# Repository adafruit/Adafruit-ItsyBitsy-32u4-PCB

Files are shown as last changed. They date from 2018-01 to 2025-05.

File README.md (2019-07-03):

## Adafruit ItsyBitsy 32u4 PCB

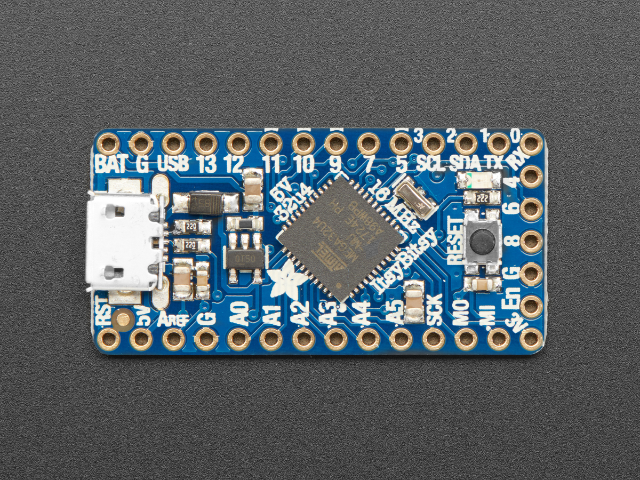
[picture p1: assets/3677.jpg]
<a href="http://www.adafruit.com/products/3677">&nbsp; 
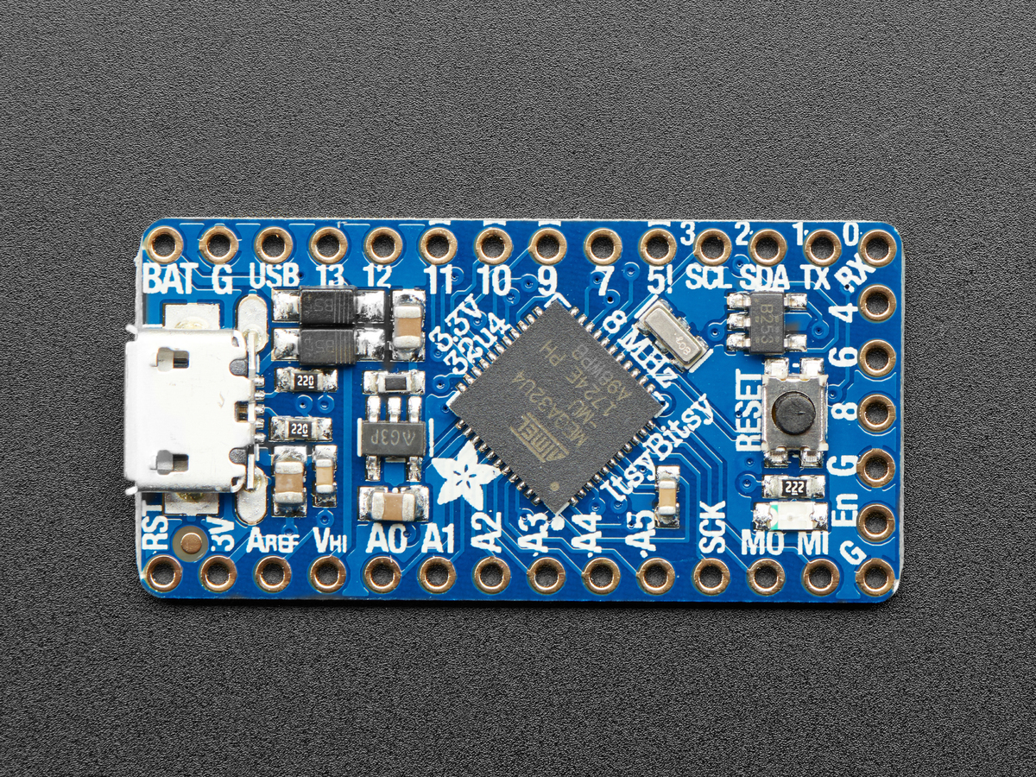
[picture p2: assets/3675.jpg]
<a href="http://www.adafruit.com/products/3675"><br/>
Click picture or links below to purchase one from the Adafruit shop</a>

PCB CAD files for the Adafruit ItsyBitsy 32u4. PCB format is EagleCAD schematic and board layout

For more details, check out the product pages at
* ItsyBitsy 32u4 - 5V 16MHz https://www.adafruit.com/products/3677
* ItsyBitsy 32u4 - 3V 8MHz https://www.adafruit.com/products/3675

### Description

What's smaller than a Feather but larger than a Trinket? It's an ItsyBitsy! Small, powerful, Arduino-compatible - this microcontroller board is perfect when you want something very compact, but still with a bunch of pins.

ItsyBitsy is only 1.4" long by 0.7" wide, but has 6 power pins, 6 analog & digital pins and 17 digital pins. It packs much of the same capability as an Arduino UNO. So it's great once you've finished up a prototype on a bigger Arduino, and want to make the project much smaller.

The ItsyBitsy 32u4 5V 16MHz and 3V 8MHz use the Atmega32u4 chip, which is the same core chip in the Arduino Leonardo as well as the same chip we use in our Feather 32u4. You'll be happy to hear that not only is ItsyBitsy programmable using the Arduino IDE as you already have set up, but a vast number of Arduino projects will work out of the box!

We recommend this as an upgrade from the Pro Trinket 5V/3V because they has native USB so it will work with all computers, USB serial debugging, and a more reliable bootloader.

### License

Adafruit invests time and resources providing this open source design, please support Adafruit and open-source hardware by purchasing products from [Adafruit](https://www.adafruit.com)!

Designed by Limor Fried/Ladyada for Adafruit Industries.

Creative Commons Attribution/Share-Alike, all text above must be included in any redistribution. See license.txt for additional details.

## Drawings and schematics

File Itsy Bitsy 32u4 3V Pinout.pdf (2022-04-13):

# Itsy Bitsy 32u4 3V @ 8MHz

# https://www.adafruit.com/product/3675

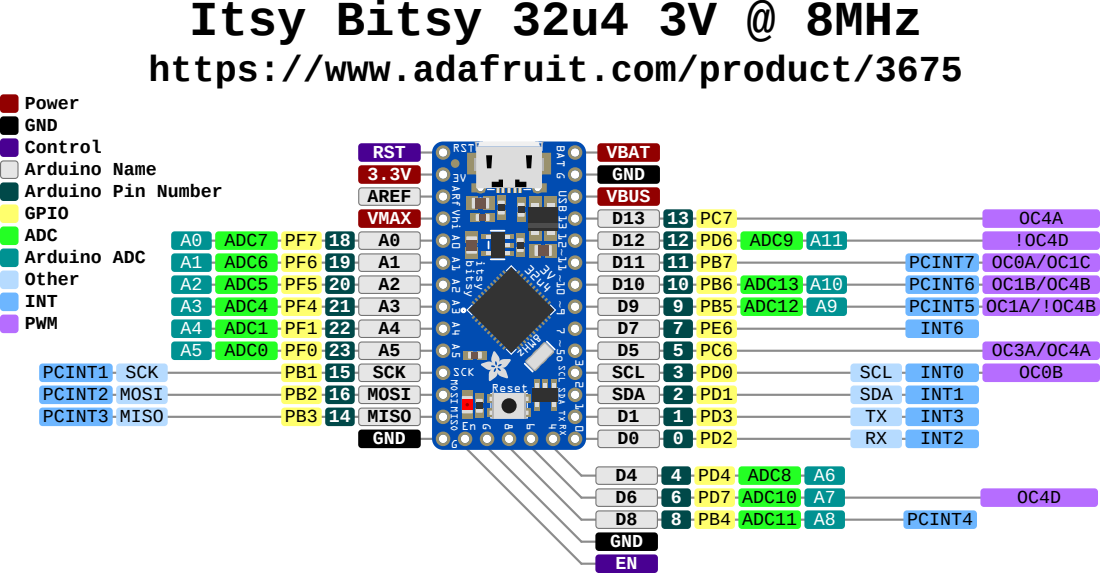
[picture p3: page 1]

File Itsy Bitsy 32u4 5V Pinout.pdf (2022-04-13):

# Itsy Bitsy 32u4 5V @ 16MHz

# https://www.adafruit.com/product/3677

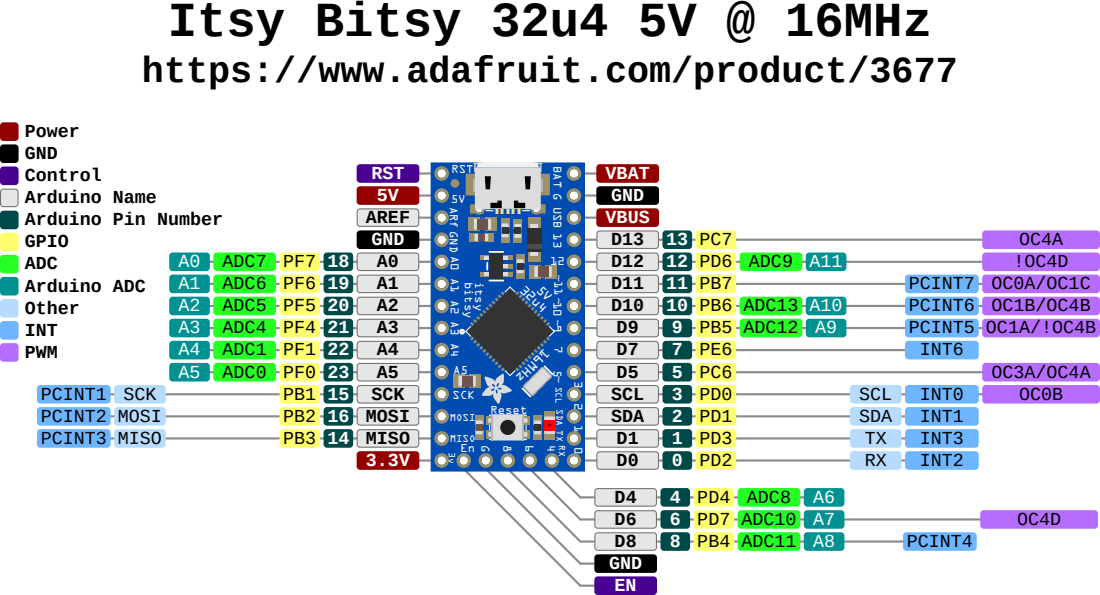
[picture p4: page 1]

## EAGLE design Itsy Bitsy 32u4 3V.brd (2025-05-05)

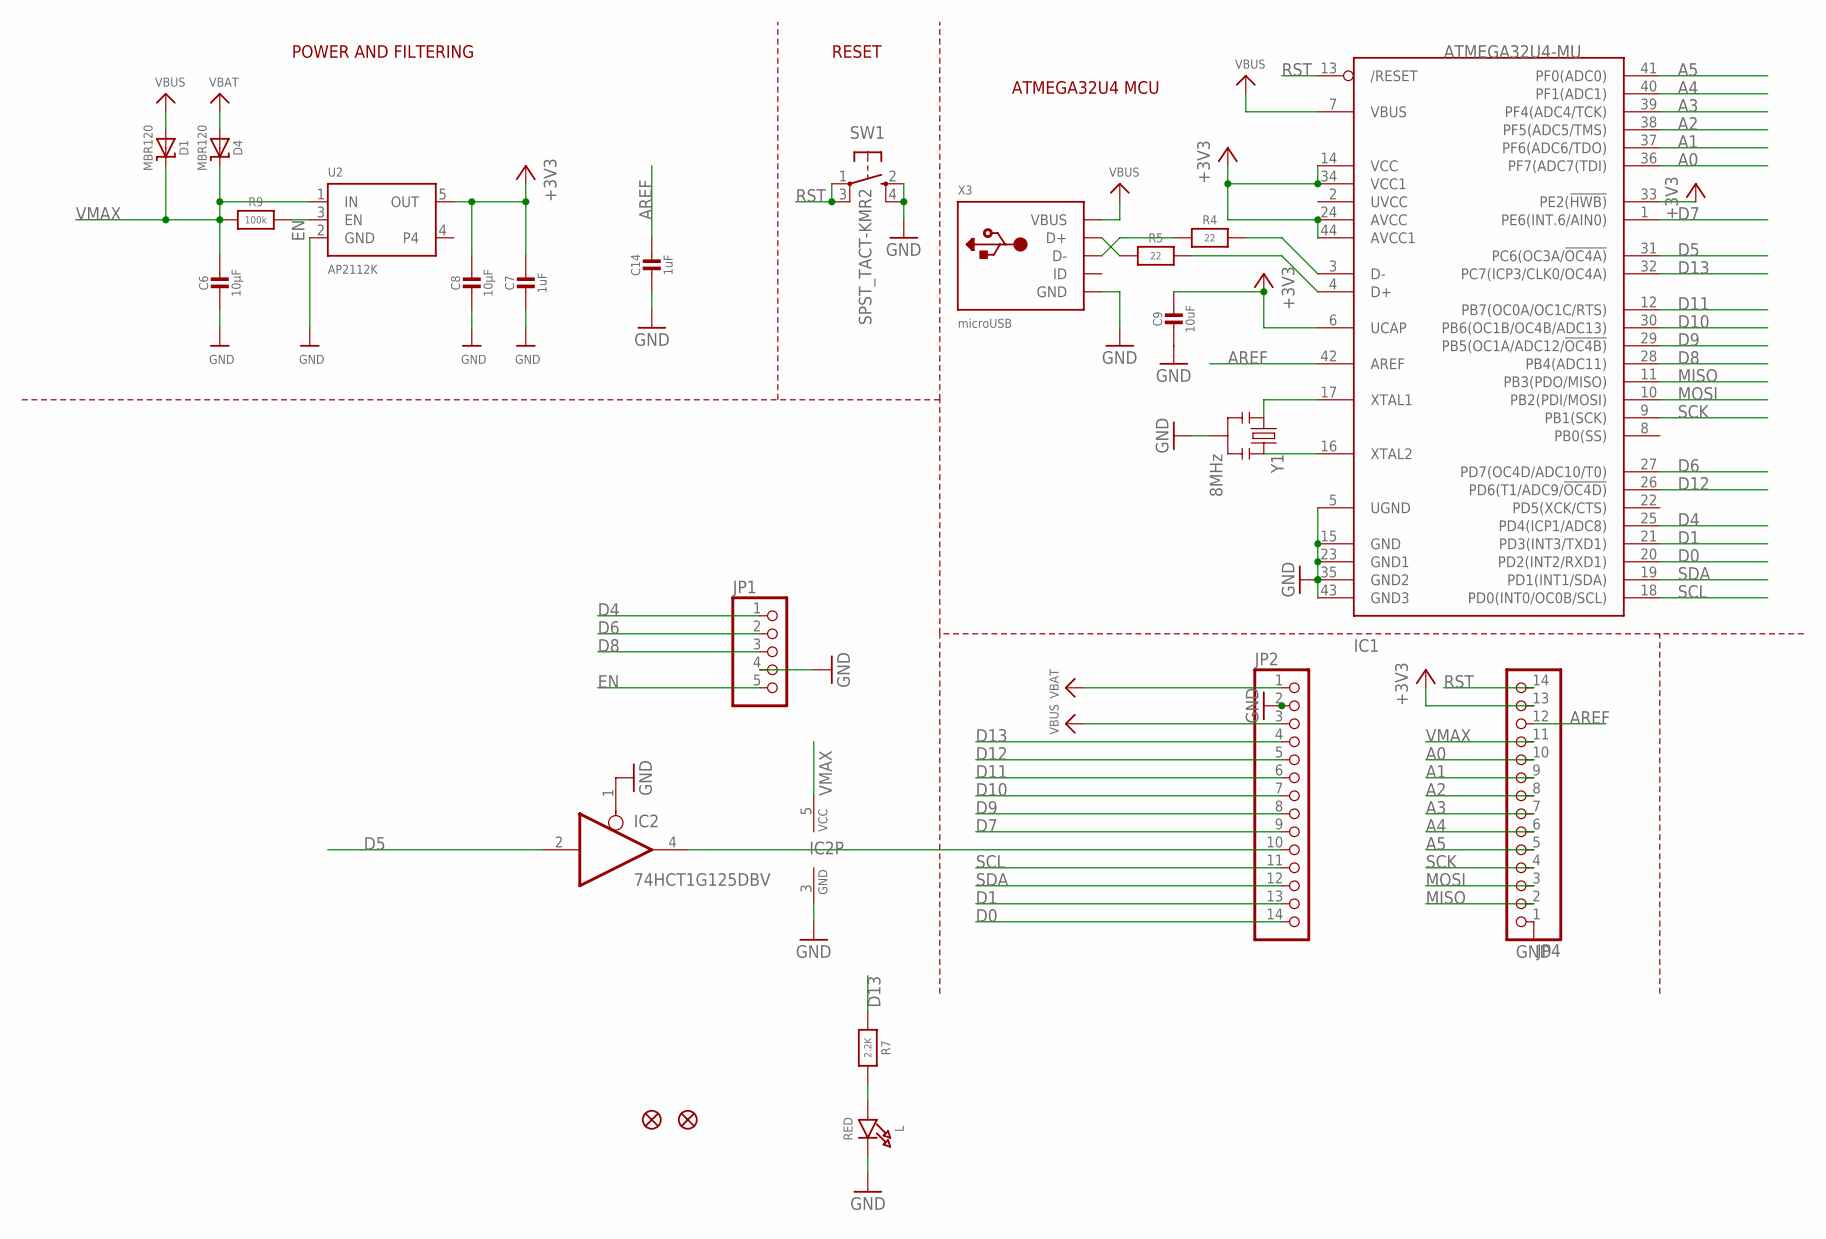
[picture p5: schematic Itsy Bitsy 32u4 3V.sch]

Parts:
C6, C8: 10µF; 0805-NO
C7, C14: 1uF; 0603-NO
C9: 10uF; 0805-NO
D1, D4: MBR120; SOD-123
IC1: ATMEGA32U4-MU; TQFN44_7MM
IC2: 74HCT1G125DBV; SOT23-5
JP1: HEADER-1X5ROUND; 1X05_ROUND
JP2, JP4: HEADER-1X14; 1X14_ROUND70
L: RED; CHIPLED_0805_NOOUTLINE
R4, R5: 22; 0603-NO
R7: 2.2K; 0603-NO
R9: 100k; 0603-NO
SW1: SPST_TACT-KMR2; KMR2
U2: AP2112K; SOT23-5
U$34, U$35: FIDUCIAL""; FIDUCIAL_1MM
X3: microUSB; 4UCONN_20329_V2
Y1: 8MHz; RESONATOR-SMD

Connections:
+3V3: C7.1, C8.1, C9.1, IC1.6 (UCAP), IC1.14 (VCC), IC1.24 (AVCC), IC1.33 (PE2(!HWB)), IC1.34 (VCC1), IC1.44 (AVCC1), JP4.13, U2.5 (OUT)
A0: IC1.36 (PF7(ADC7(TDI)), JP4.10
A1: IC1.37 (PF6(ADC6/TDO)), JP4.9
A2: IC1.38 (PF5(ADC5/TMS)), JP4.8
A3: IC1.39 (PF4(ADC4/TCK)), JP4.7
A4: IC1.40 (PF1(ADC1)), JP4.6
A5: IC1.41 (PF0(ADC0)), JP4.5
AREF: C14.1, IC1.42 (AREF), JP4.12
D0: IC1.20 (PD2(INT2/RXD1)), JP2.14
D1: IC1.21 (PD3(INT3/TXD1)), JP2.13
D4: IC1.25 (PD4(ICP1/ADC8)), JP1.1
D5: IC1.31 (PC6(OC3A/!OC4A)), IC2.2 (I)
D5_OUT: IC2.4 (O), JP2.10
D6: IC1.27 (PD7(OC4D/ADC10/T0)), JP1.2
D7: IC1.1 (PE6(INT.6/AIN0)), JP2.9
D8: IC1.28 (PB4(ADC11)), JP1.3
D9: IC1.29 (PB5(OC1A/ADC12/!OC4B)), JP2.8
D10: IC1.30 (PB6(OC1B/OC4B/ADC13)), JP2.7
D11: IC1.12 (PB7(OC0A/OC1C/RTS)), JP2.6
D12: IC1.26 (PD6(T1/ADC9/!OC4D)), JP2.5
D13: IC1.32 (PC7(ICP3/CLK0/OC4A)), JP2.4, R7.1
D+: IC1.4 (D+), R5.2
D-: IC1.3 (D-), R4.2
EN: JP1.5, R9.2, U2.3 (EN)
GND: C6.2, C7.2, C8.2, C9.2, C14.2, IC1.5 (UGND), IC1.15 (GND), IC1.23 (GND1), IC1.35 (GND2), IC1.43 (GND3), IC2.1 (OE), IC2.3 (GND), JP1.4, JP2.2, JP4.1, L.C, SW1.2 (S), SW1.4 (S1), U2.2 (GND), X3.BASE@1 (GND), X3.BASE@2 (GND), X3.GND, X3.SPRT@1 (GND), X3.SPRT@2 (GND), X3.SPRT@3 (GND), X3.SPRT@4 (GND), Y1.2
MISO: IC1.11 (PB3(PDO/MISO)), JP4.2
MOSI: IC1.10 (PB2(PDI/MOSI)), JP4.3
unnamed: L.A, R7.2
unnamed: IC1.16 (XTAL2), Y1.3
unnamed: IC1.17 (XTAL1), Y1.1
unnamed: R5.1, X3.D+
unnamed: R4.1, X3.D-
RST: IC1.13 (/RESET), JP4.14, SW1.1, SW1.3 (P1)
SCK: IC1.9 (PB1(SCK)), JP4.4
SCL: IC1.18 (PD0(INT0/OC0B/SCL)), JP2.11
SDA: IC1.19 (PD1(INT1/SDA)), JP2.12
VBAT: D4.A, JP2.1
VBUS: D1.A, IC1.7 (VBUS), JP2.3, X3.VBUS
VMAX: C6.1, D1.C, D4.C, IC2.5 (VCC), JP4.11, R9.1, U2.1 (IN)

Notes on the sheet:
POWER AND FILTERING
RESET
ATMEGA32U4 MCU

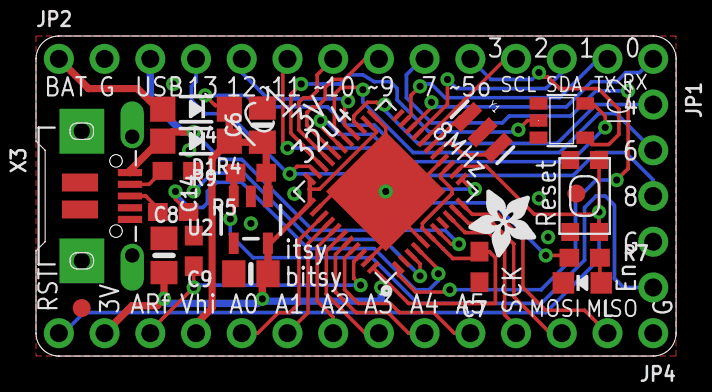
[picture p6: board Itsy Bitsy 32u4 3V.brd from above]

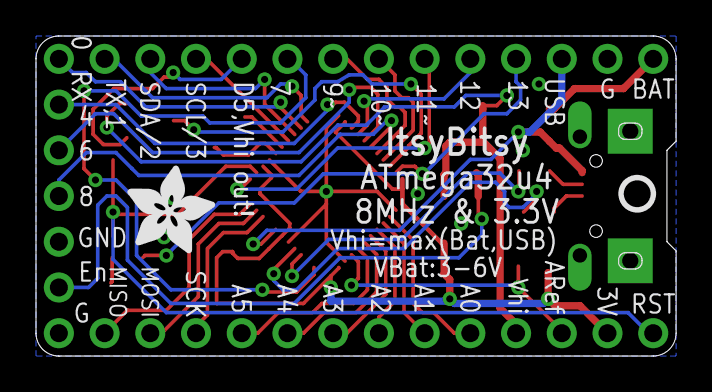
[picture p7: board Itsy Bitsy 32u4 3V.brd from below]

Board: 2 copper layers, 35.6 x 17.8 mm, 26 parts (2 on the bottom side), 39 nets.

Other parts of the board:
U$2: PCBFEAT-REV-040
U$4: ADAFRUIT_5MM
U$7: ADAFRUIT_3.5MM

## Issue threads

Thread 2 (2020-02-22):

error opening schematic

K2AAE, 2020-02-22:
Loading D:/git/Adafruit-ItsyBitsy-32u4-PCB/Itsy Bitsy 32u4 5V.sch ...

Warning(s):

line 3926: ignoring redefinition of pinref to part 'JP2', gate 'G$1', pin '2'

ladyada, 2020-02-22:
thats a warning, not an error

Closed 2020-02-22.

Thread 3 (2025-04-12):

Incorrect power regulator on the ItsyBitsy 32u4 - 3V schematics.

a474c, 2025-04-12:
I’m not an expert, so please correct me if I’m wrong, but I think there might be an issue with the ItsyBitsy 32u4 3V schematic files. The product description states that the 3v version comes equipped with a regulator capable of delivering up to 500mA at 3.3v:
"On-board 3.3V power regulator with 500mA output capability and ultra-low dropout." [https://www.adafruit.com/product/3675](https://www.adafruit.com/product/3675)

The same information can also be found in the learning guide:
"3V - this is the regulated output from the onboard regulator. You can draw 500mA whether powered by USB or battery." [https://learn.adafruit.com/introducting-itsy-bitsy-32u4/pinouts](https://learn.adafruit.com/introducting-itsy-bitsy-32u4/pinouts)

According to the diagram, the regulator in the 3v version is a MIC5225-3.3.
"The MIC5225 is a **150 mA**, highly accurate low dropout regulator with high input voltage and ultra-low ground current." [https://www.microchip.com/en-us/product/MIC5225](https://www.microchip.com/en-us/product/MIC5225)

The board photos show a component labelled ‘G3P’. It appears to be an AP2112K-3.3TRG1, which is indeed a 600mA 3.3v regulator. [https://www.diodes.com/assets/Datasheets/AP2112.pdf](https://www.diodes.com/assets/Datasheets/AP2112.pdf)

Thanks! :)

ladyada, 2025-05-04:
hiya th 3V version has a 3.3V 500mA regulator (AP2112K) the 5V version has the MIC5225!

ladyada, 2025-05-04:
kk @BlitzCityDIY can you tweak

Closed 2025-05-05.

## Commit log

2018-01-02 itsy bitsy 32u4 files!
    [Itsy Bitsy 32u4 3V.brd, Itsy Bitsy 32u4 3V.sch, Itsy Bitsy 32u4 5V.brd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]
2025-05-05 update 3V regulator label
    [Itsy Bitsy 32u4 3V.brd, Itsy Bitsy 32u4 3V.sch]

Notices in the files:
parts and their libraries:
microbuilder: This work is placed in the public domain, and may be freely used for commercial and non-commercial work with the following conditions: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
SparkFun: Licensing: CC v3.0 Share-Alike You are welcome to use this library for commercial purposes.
